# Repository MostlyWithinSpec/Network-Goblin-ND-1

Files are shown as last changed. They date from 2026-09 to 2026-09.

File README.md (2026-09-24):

<div align="center">

# 🧌 Network Goblin ND-1

### *"Here be packets."*

**A DIY handheld Ethernet cable & network tester built around a ~$2 PHY chip.**

Cable fault detection (TDR), length estimation, link / DHCP / ping / traceroute,
and switch-port identification (LLDP/CDP) — on a touchscreen, in your pocket,
for a fraction of the cost of a commercial LinkRunner or Pockethernet.

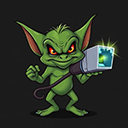
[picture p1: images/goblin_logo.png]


</div>

---

## What is it?

The Network Goblin is a homemade network technician's tool. Plug it into a
drop and it tells you what's wrong with the cable or the connection: is the
cable broken, where's the break, is it linking, is it getting DHCP, can it
reach the gateway and the internet, and *which switch port am I plugged into*.

It's built on the surprising discovery that the **Microchip LAN8742**
Ethernet PHY has a built-in **TDR (Time Domain Reflectometry)** engine — the
same technique the expensive testers use to locate cable faults — that you
can drive directly over the PHY management bus. Pair that with an ESP32, a
touchscreen, and a battery, and you've got a real cable tester for pocket
change.

> ⚠️ **Project status: working prototype.** The dev-kit build is fully
> functional. A custom PCB is in development. This is an active,
> learning-in-public hobby project — expect rough edges.

---

## ✨ Features

### Working now
- ✅ **Cable fault detection (TDR)** — detects **OPEN / SHORT / GOOD** on the
  two active pairs and reports **distance to the fault** in feet.
- ✅ **Per-pair status** — pairs 1-2 and 3-6 tested individually.
- ✅ **Link status** — up/down, 10/100, full/half duplex.
- ✅ **DHCP test** — IP, subnet, gateway, DNS.
- ✅ **Ping** — gateway and Google (8.8.8.8), one tap, no typing.
- ✅ **Traceroute** — gateway and Google.
- ✅ **Switch identification (LLDP / CDP)** — discovers the **switch name,
  port, and VLAN** you're plugged into. Works with a temporary capture that
  pauses networking, then restores it automatically.
- ✅ **Port flash** — blinks the switch's port LED (by cycling the link) so
  you can physically find which port your cable goes to. No SNMP or creds.
- ✅ **AutoTest** — one button: checks the cable, and if it's good, pings the
  gateway and internet, then shows a PASS/FAIL rollup + cable length.
- ✅ **Touchscreen GUI** (LVGL) with a light "business" theme and a dark
  "goblin" hacker theme.
- ✅ **Serial console** — every function is also available over USB serial
  (`id`, `link`, `cable`, `tdr`, `pairs`, `ping <host>`, `trace <host>`,
  `switch`, `flash`).
- ✅ **Settings persistence** — remember theme, units, calibration.

### Known limitations / rough edges
- ⚠️ **Linked-cable length needs tuning.** When plugged into a live switch,
  cable length comes from the PHY's CBLN register, which is *coarse* and
  currently **over-reports** (an ~18 ft cable may read ~100 ft). It needs
  per-chip calibration against known cable lengths. **Open-cable (TDR) fault
  distance is accurate**; linked-length is a rough estimate for now.
- ⚠️ **Switch ID and networking are mutually exclusive** — identifying the
  switch pauses networking for ~45s, then restores it. (By design; keeps it
  rock-solid.)
- ⚠️ **Port flash is switch-dependent** — the link *does* cycle, but some
  switches (many UniFi/UBNT) don't visibly blink the port LED on link loss.
  Cisco and most managed switches will.
- ⚠️ **Traceroute** doesn't yet display intermediate hop addresses reliably.
- ⚠️ **Pairs 4-5 and 7-8** can't be tested at 10/100 (those pairs aren't
  driven). Shown honestly as "n/a." Full 4-pair wiremap needs a gigabit PHY.
- ⚠️ **No battery gauge** on the dev-kit build (planned for the custom PCB).

### Planned / roadmap
- 🔜 **Custom destination** for ping / traceroute (on-screen entry).
- 🔜 **Linked-length calibration** baked in.
- 🔜 **Battery percentage** (custom PCB).
- 🔜 **Screenshot / result logging to SD.**

### The bigger idea — "ND-2"
A future, more powerful sibling based on a Linux SBC (e.g. an Orange Pi with
a gigabit NIC): real 4-pair certification, packet capture / Wireshark,
iperf throughput, inline tap / port-mirror target, and security-oriented
tooling. ND-1 stays the cheap, instant-on pocket tester; ND-2 is the
Linux-powered multitool. (Concept stage.)

---

## 🛠️ Hardware

🎉**Ordered Rev-c boards on 9/24/2026** Don't buy the PCB yet. I will update if the board is stable and working.

This runs today on an **off-the-shelf dev-kit build** — no custom PCB
required to try it. A custom board is in testing.

### Dev-kit build (replicate it now)
| Part | Notes |
|---|---|
| **ESP32 DevKit (WROOM-32)** | Must be the *classic* ESP32 — it has the built-in Ethernet MAC. **NOT** S3 / S2 / C3 (no EMAC). |
| **LAN8720 RMII module, chip-swapped to LAN8742** | The LAN8742 is footprint-compatible with the LAN8720. Desolder the 8720, reflow an 8742 in its place. This is what gives you the TDR engine. |
| **3.5" SPI touchscreen** | ST7796 driver, FT6336U capacitive touch, 320×480. |
| **Jumper wires / breadboard** | For the RMII + display wiring. |
| **(optional) LiPo + charger** | For untethered use. |

> 🔧 **Two gotchas worth knowing:**
> - The chip swap is a QFN reflow. Doable with hot air + flux + patience
>   (this project's first swap was done one-handed in a sling — it's
>   forgiving). Buy a couple of LAN8742s for spares, and mind orientation.
> - If using the same Elegoo-style ESP32, you'll need to **solder a wire to
>   GPIO0** for the PHY REFCLK.

### Parts list (dev kit)
| Part | Link |
|---|---|
| ESP32 WROOM | https://a.co/d/03k8Kfh2 |
| LAN8720 module | https://a.co/d/0iP2sltR |
| LAN8742A chip | https://ebay.io/m/x2hki5 |
| 3.5" LCD | https://www.aliexpress.us/item/3256805925926605.html |

### Wiring (dev kit)
RMII data pins on the ESP32 are **fixed in silicon**:
```
TXD0=19  TXD1=22  TX_EN=21   RXD0=25  RXD1=26  CRS_DV=27
MDC=23   MDIO=18  50 MHz CLK -> GPIO0 (from the module's oscillator)
PHY address strap = 1
```
Display / touch pins are configurable — see `ng_config.h` (all pins live in
one place; edit there first).

> ⚠️ **The GPIO0 clock quirk:** the module's 50 MHz clock feeds GPIO0, which 
> is also the boot strap pin. You can usually flash with the clock wire 
> **still connected** — but it occasionally gets stuck holding GPIO0 low at 
> boot. If a flash fails or it hangs, just **tap reset a few times** until it 
> catches and boots/uploads normally. (The custom PCB fixes this for good.)

### Custom PCB (in development)
A dedicated board with the LAN8742, ESP32, display connector, LiPo charging,
and a proper power switch is being designed. It is **not fully working yet**
(hardware bring-up in progress). Beta board files will be posted shortly.

> ⚠️ **Not recommended to order the PCB yet** — there are several known
> issues. Watch the repo; files and a BOM will come once it's validated.

---

## 💾 Firmware (Arduino)

Built with the **Arduino IDE** and **LVGL**.

### Requirements
- Arduino IDE 2.x
- **esp32 board package** (Espressif) — v3.x
- Libraries (Library Manager):
  - **lvgl** (9.x)
  - **GFX Library for Arduino** (Arduino_GFX by moononournation)
- An `lv_conf.h` configured for LVGL 9 (see LVGL's Arduino setup notes)

### Build
1. Open the `ND1_Goblin_LVGL` folder in Arduino IDE.
2. Board: **ESP32 Dev Module**. Upload speed: 115200.
3. Edit `ng_config.h` to match your wiring.
4. Upload. If it fails to connect or hangs at boot, tap reset a few times until it catches (The GUI will flash in very quickly during boot. This is how you know it is not stuck in boot low).
5. Serial Monitor @ 115200. Type `help` for commands.

First boot should print the PHY ID (`0x0007C131` for a LAN8742) — that
confirms the chip swap worked.

---

### Screenshots
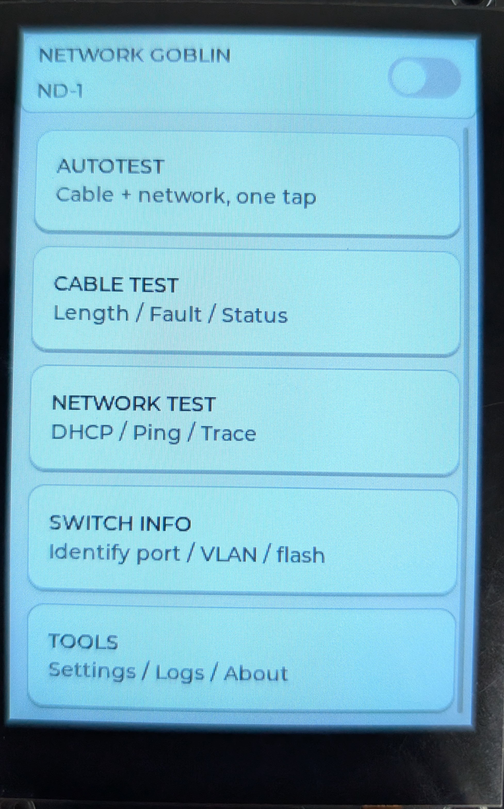
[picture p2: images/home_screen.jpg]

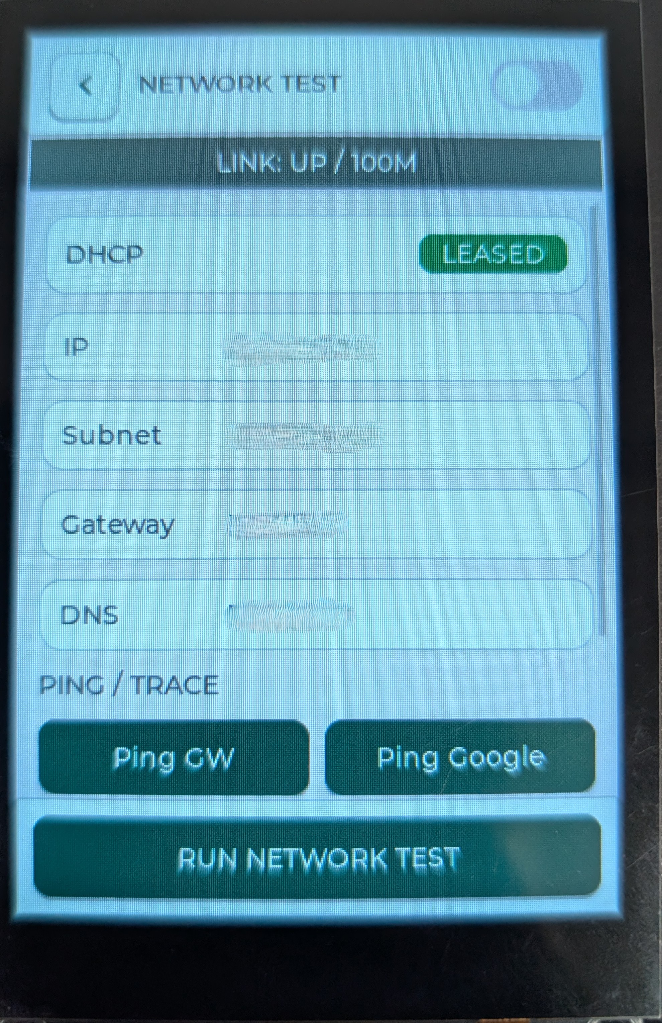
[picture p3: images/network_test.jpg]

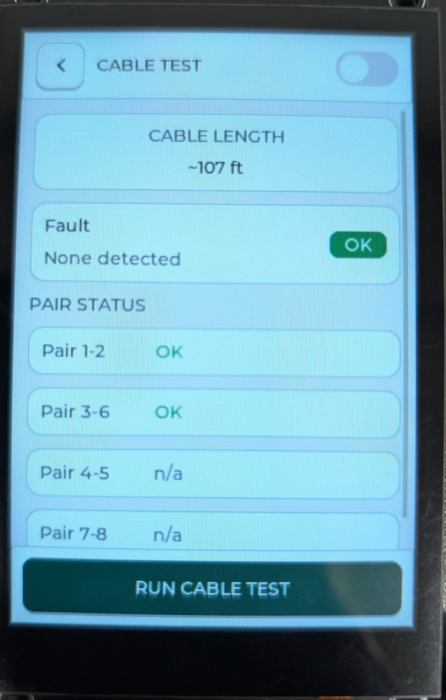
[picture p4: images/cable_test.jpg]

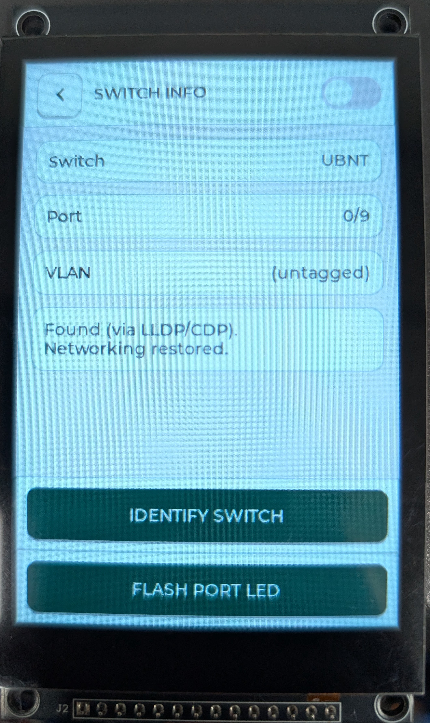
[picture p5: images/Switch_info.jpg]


## 📁 Repo layout
```
network-goblin/
├── README.md
├── LICENSE
├── CONTRIBUTING.md
├── .gitignore
├── images/                   (screenshots / build photos)
└── ND1_Goblin_LVGL/          (open this folder in Arduino IDE)
    ├── ND1_Goblin_LVGL.ino   main sketch (boot + loop + serial console)
    ├── ng_config.h           ALL pins / tunables — edit first
    ├── ng_eth.*              Ethernet (LAN8742) + PHY MDIO + cable length
    ├── ng_tdr.*              TDR cable fault detection (the heart of it)
    ├── ng_pairs.*            per-pair status
    ├── ng_netcmd.*           ping + traceroute
    ├── ng_lldp.*             LLDP/CDP switch ID + port flash
    ├── ng_display.*          LVGL + ST7796 + FT6336U
    └── ng_ui.*               the touchscreen UI (hand-coded LVGL)
```

---

## 🧪 A note on accuracy

This is a **hobby tool, not a certified cable analyzer.** The TDR fault
distance is calibrated against a handful of known cables and gets you
"close" — great for *finding a break*, not for certification. Linked-cable
length (CBLN) is coarse and needs tuning. Treat readings as a very useful
sanity check, not gospel. If you need certified results, buy the $2,000
tool. If you want to know "is this drop broken, and roughly where" for the
price of a nice dinner — welcome to the Goblin. 🧌

---

## 🤝 Contributing

This is an active, learning-in-public project by a self-taught tinkerer.
Issues, PRs, ideas, and "you did this the hard way, here's better" comments
are all welcome. If you build one, I'd love to see it. See
[CONTRIBUTING.md](CONTRIBUTING.md).

> Full disclosure: a lot of this was built with heavy help from AI as a
> learning aid. It's a hobbyist's project, shared openly. Improvements from
> people who actually know what they're doing are very welcome.

## 📜 License

**MIT** — see [LICENSE](LICENSE). Do whatever you want with it. No warranty.
Don't blame the goblin if your cable's still broken.

---

<div align="center">

*Built one-handed, in a sling, after shoulder surgery, out of spite for a
$2,000 price tag. The Goblin endures.* 🧌🔌⚡

</div>

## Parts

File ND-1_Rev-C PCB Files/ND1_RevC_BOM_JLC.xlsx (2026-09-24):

Comment | Designator | Footprint | JLCPCB Part #（optional）
470pF | C1 | C0603 | C107092
1uF | C2 | C0603 | C29936
100nF | C3,C4,C7,C8,C16,C21,C22,C24,C26,C27,C28,C29,C30 | C0603 | C14663
10uF | C9,C10,C11 | C0805 | C15850
22uF | C12,C13,C14,C15,C25 | C0805 | C45783
1uF | C17,C20,C23 | C0603 | C15849
4.7uF | C18,C19 | C0805 | C1779
1.25-2P | CN2 | CONN-SMD_1.25-2P | C393945
BAT54WS | D1 | D_SOD-323 | C124205
HR911105A | J1 | RJ45-TH_HR911105A | C12074
1.5uH | L1 | IND-SMD_L4.0-W4.0-A | C3033018
MMBT5551(RANGE:200-300) | Q1 | SOT-23-3_L2.9-W1.3-P1.90-LS2.4-BR | C2145
10kΩ | R1,R2,R9,R11,R12,R34,R40,R45,R46,R47 | R0603 | C25804
1.5kΩ | R3 | R0603 | C2930050
12.1kΩ | R4 | R0603 | C2930059
2kΩ | R13 | R0603 | C22975
4.7kΩ | R14,R17,R18 | R0402 | C25900
1.27kΩ | R15 | R0603 | C22836
47kΩ | R16,R33 | R0603 | C25819
5.1kΩ | R21,R22 | R0402 | C25905
180kΩ | R23 | R0603 | C22827
49.9Ω | R25,R28,R29,R30 | R0402 | C25120
1MΩ | R27 | R0603 | C22935
33Ω | R31,R32 | R_0603_1608Metric | C23140
470Ω | R35 | R_0603_1608Metric | C23179
10Ω | R36,R37,R38 | R_0402_1005Metric | C25077
4.7kΩ | R39 | R_0603_1608Metric | C23162
332Ω | R41,R42 | R_0603_1608Metric | C23007
100kΩ | R43,R44,R48 | R_0603_1608Metric | C25803
TS-1187A-B-A-B | SW1,SW2 | SW-SMD_4P-L5.1-W5.1-P3.70-LS6.5-TL_H1.5 | C318884
PWR (EN switch) | SW3 | SW_SPDT_PCM12 | C221841
ESP32-WROVER-E-N16R8 | U1 | WIFI-SMD_ESP32-WROVER-E | C529589
LAN8742A-CZ-TR | U2 | QFN-24_L4.0-W4.0-P0.50-TL-EP2.5 | C621424
CH9102F | U3 | QFN-24_L4.0-W4.0-P0.50-BL-EP2.5 | C2858418
BQ24074RGTR | U4 | QFN-16_L3.0-W3.0-P0.50-TL-EP1.7 | C54313
TPS63020DSJR | U5 | VSON-14_L4.0-W3.0-P0.50-BL-EP_TI_DSJ | C15483
MAX17048G+T10 | U6 | TDFN-8_L2.0-W2.0-P0.50-BL-EP1.2 | C2682616
FPC 0.5-14P HYH2.0 | U7 | FPC-SMD_14P-P0.50_FPC-0.5-14P-HYH2.0 | C6364661
MMZ1608Y152BTA00 | U8 | L0603 | C275454
SRV05-4 | U9 | SOT-23-6 | C13612
74LVC2G126 | U10 | VSSOP-8_2.3x2mm_P0.5mm | C2652104
TYPE-C-31-M-12 | USBC1 | USB-C_SMD-TYPE-C-31-M-12_1 | C165948
50MHz | Y1 | Oscillator_SMD_Abracon_ASE-4Pin_3.2x2.5mm | C717684

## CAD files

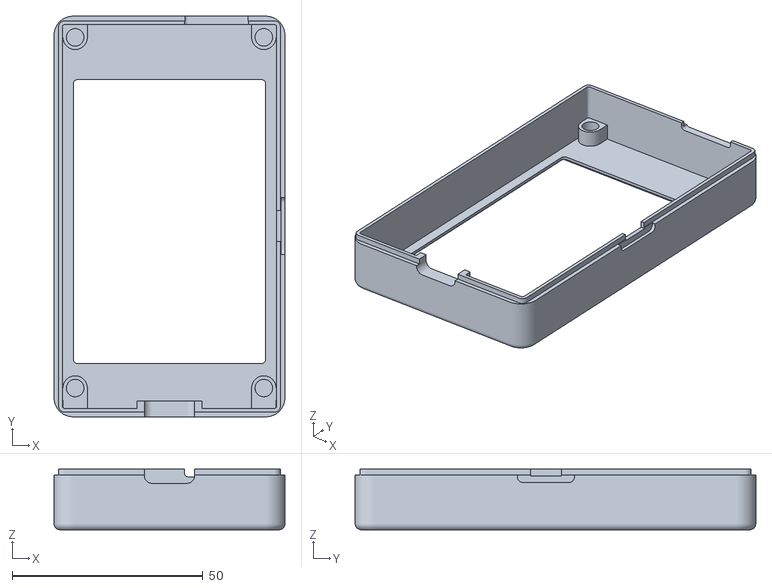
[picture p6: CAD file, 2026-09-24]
ND1_RevC_Case_Files/ND1_FrontShell.stl
60.6 x 105.1 x 15.9

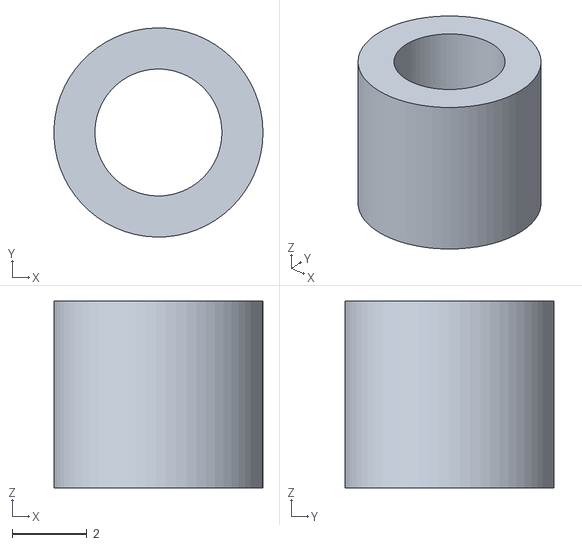
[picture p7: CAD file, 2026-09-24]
ND1_RevC_Case_Files/ND1_Spacer_print_x4.stl
5.60 x 5.60 x 5.00

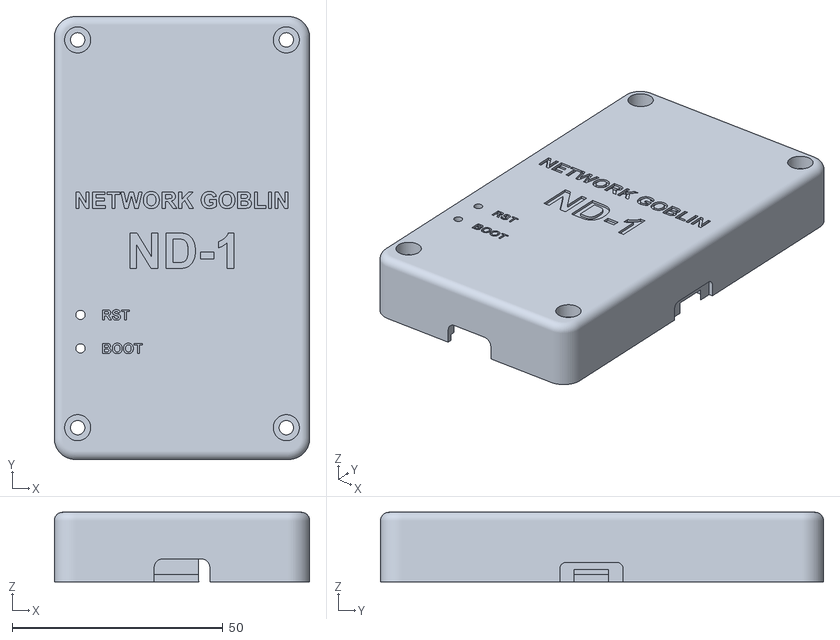
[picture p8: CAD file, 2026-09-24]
ND1_RevC_Case_Files/ND1_BackCover.stl
60.6 x 105.1 x 16.5

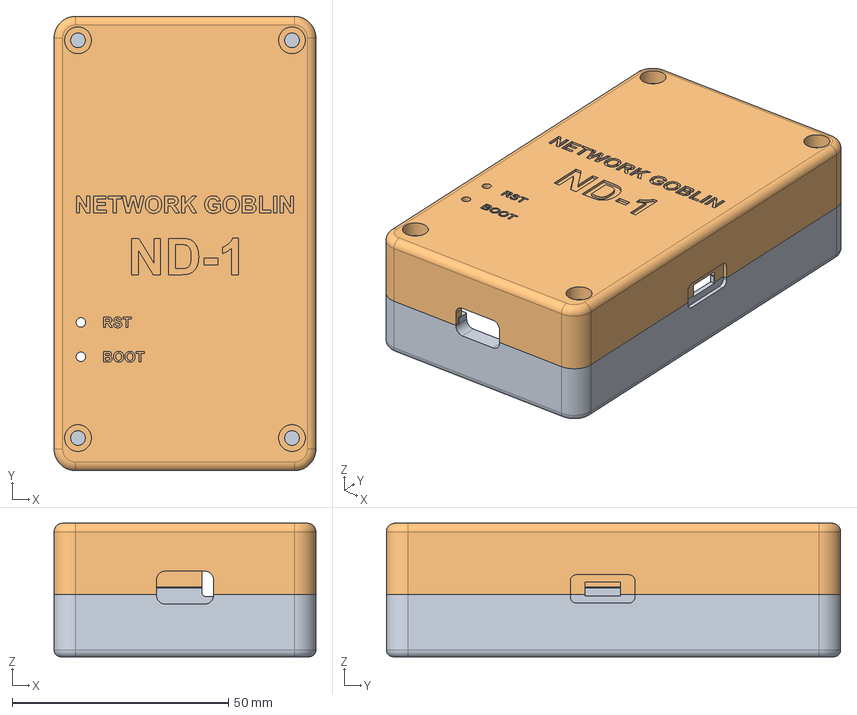
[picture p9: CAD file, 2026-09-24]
ND1_RevC_Case_Files/ND1_Case_parts.step
60.6 x 105.1 x 30.9 mm
FrontShell
BackCover
Spacer

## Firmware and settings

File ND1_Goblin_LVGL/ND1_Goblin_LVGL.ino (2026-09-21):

/* ============================================================
 *  Network Goblin ND-1  -  Arduino + LVGL firmware
 *  "Here be packets."
 * ------------------------------------------------------------
 *  Serial commands: id | link | cable | tdr | pairs | switch 
                  | Flash | ping <host> | trace <host> | help
 * ============================================================ */
#include "ng_config.h"
#include "ng_eth.h"
#include "ng_tdr.h"
#include "ng_pairs.h"
#include "ng_netcmd.h"
#include "ng_display.h"
#include "ng_ui.h"
#include "ng_lldp.h" 
#include "ng_goblin.h"
#include "Preferences.h"

static void banner(){
  Serial.println();
  Serial.println("=====================================");
  Serial.printf (" NETWORK GOBLIN %s  fw %s\n", NG_MODEL, NG_FW);
  Serial.println(" " NG_TAGLINE);
  Serial.println("=====================================");
}

static void serialCmd(){
  static char buf[40]; static uint8_t n=0;
  while(Serial.available()){
    char c=Serial.read();
    if(c=='\n'||c=='\r'){ buf[n]=0;
      if(!strcmp(buf,"id")){ uint32_t id; if(ngPhyId(&id)) Serial.printf("[PHY] ID=0x%08X OK\n",id); else Serial.println("[PHY] read FAILED"); }
      else if(!strcmp(buf,"link")){ NgCable c2; ngCableRun(c2); Serial.printf("[LINK] %s %dMbps %s\n",c2.state,c2.speed_mbps,c2.full_duplex?"FULL":"HALF"); }
      else if(!strcmp(buf,"cable")){ NgCable c2; ngCableRun(c2); Serial.printf("[CABLE] %s len=%s cbln=0x%04X\n",c2.state,c2.length_valid?String(c2.length_ft,0).c_str():"--",c2.raw_cbln); }
      else if(!strcmp(buf,"tdr")){ NgTdrResult r; ngTdrRun(r);
        Serial.printf("MDI : %-6s ~%.1f ft [0x%04X]\n",ngTdrTypeStr(r.mdi.type),r.mdi.dist_ft,r.mdi.raw25);
        Serial.printf("MDIX: %-6s ~%.1f ft [0x%04X]\n",ngTdrTypeStr(r.mdix.type),r.mdix.dist_ft,r.mdix.raw25); }
      else if(!strcmp(buf,"pairs")){ NgWiremap w; ngPairsRun(w);
        Serial.printf("Pair 1-2: %s\n",ngPairStateStr(w.p12.state));
        Serial.printf("Pair 3-6: %s\n",ngPairStateStr(w.p36.state));
        Serial.printf("Pair 4-5: %s\n",ngPairStateStr(w.p45.state));
        Serial.printf("Pair 7-8: %s\n",ngPairStateStr(w.p78.state)); }
      else if(!strncmp(buf,"ping ",5)){ NgPingResult pr;
        if(ngPing(buf+5,4,pr)) Serial.printf("ping %s (%s): %d/%d avg %lums (min %lu/max %lu)\n",buf+5,pr.resolved_ip.c_str(),pr.recv,pr.sent,pr.avg_ms,pr.min_ms,pr.max_ms);
        else Serial.printf("ping %s: no reply\n",buf+5); }
      else if(!strncmp(buf,"trace ",6)){ Serial.printf("traceroute to %s:\n",buf+6);
        ngTraceroute(buf+6,20,[](int hop,const char* ip,uint32_t rtt,bool reached){ Serial.printf(" %2d  %-16s %lums%s\n",hop,ip,rtt,reached?"  <-- dest":""); }); }
    else if(!strcmp(buf,"switch")){
  Serial.println("[SWITCH] listening 45s (networking paused)...");
  ngLldpStart();
  uint32_t t0=millis();
  while(millis()-t0 < 45000 && !ngLldpFresh(60000)){ delay(200); }
  NgSwitchInfo si; ngLldpGet(si);
  if(si.have_lldp||si.have_cdp){
    Serial.printf("[SWITCH] name: %s\n", si.sys_name[0]?si.sys_name:"?");
    Serial.printf("[SWITCH] port: %s\n", si.port_id[0]?si.port_id:"?");
    Serial.printf("[SWITCH] vlan: %d\n", si.vlan);
  } else Serial.println("[SWITCH] nothing seen (try again / check LLDP enabled)");
  ngLldpStop();   // <-- restores networking
}
else if(!strcmp(buf,"flash")){ ngLldpPortFlash(5); }
else if(!strcmp(buf,"netcheck")){ ngLldpEnsureStopped();
  NgNet n; ngEthSnapshot(n); Serial.printf("IP: %s\n", n.got_ip?n.ip.c_str():"none"); }
      else if(!strcmp(buf,"help")){ Serial.println("cmds: id | link | cable | tdr | pairs | switch | Flash | ping <host> | trace <host> | help"); }
      else if(n>0) Serial.println("? help");
      n=0;
    } else if(n<sizeof(buf)-1) buf[n++]=c;
  }
}

void setup(){
  Serial.begin(115200);
  delay(300);

  banner();

  ngGoblinInit();

  Serial.println("[SYS] display...");
  ngDisplayBegin();

  Serial.println("[SYS] ui...");
  ngUiInit();

  ngUiShowSplash();
  ngUiSplashStatus("Initializing Ethernet...");

  Serial.println("[SYS] ethernet...");
  ngEthBegin();

  ngLldpBegin();

  uint32_t id;

  if(ngPhyId(&id)){
    Serial.printf("[PHY] ID=0x%08X swap OK\n",id);

    ngUiSplashStatus(
      "PHY........OK\n"
      "Display....OK\n"
      "Network....OK"
    );
  }

  delay(500);

  ngUiSplashAwake();

  delay(1000);

  ngUiLoadHome();

  Serial.println("[SYS] up. type 'help'. Goblin awake.");
}

void loop(){
  ngDisplayTick();
  ngUiService();
  serialCmd();
}

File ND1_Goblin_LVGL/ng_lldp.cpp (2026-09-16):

/* ng_lldp.cpp - LLDP / CDP discovery + port flash  (v3 - on-demand)
 * ------------------------------------------------------------
 *  Capture is ON-DEMAND and MUTUALLY EXCLUSIVE with networking.
 *
 *    ngLldpStart()  -> installs a frame hook that CONSUMES frames.
 *                      Networking (DHCP/ping) is paused while active.
 *    ngLldpStop()   -> removes the hook and RESTARTS Ethernet so the
 *                      normal stack works again. No frame-forwarding
 *                      trickery needed - we just rebuild the driver.
 *
 *  Any other tool (network test, ping, etc.) should call
 *  ngLldpEnsureStopped() first, which restores networking if a
 *  capture was left running.
 *
 *  This trades "both at once" for "rock solid" - exactly the tradeoff
 *  you asked for.
 * ============================================================ */
#include "ng_lldp.h"
#include "ng_config.h"
#include <WiFi.h>
#include <ETH.h>
#include "esp_eth.h"
#include "freertos/FreeRTOS.h"
#include "freertos/task.h"
#include <string.h>

extern bool ngPhyRead(uint8_t reg, uint16_t* val);
extern bool ngPhyWrite(uint8_t reg, uint16_t val);

static NgSwitchInfo s_info;
static portMUX_TYPE s_mux = portMUX_INITIALIZER_UNLOCKED;
static esp_eth_handle_t s_eth = NULL;
static volatile bool s_flashing = false;
static volatile bool s_capturing = false;

static uint16_t be16(const uint8_t* b){ return ((uint16_t)b[0]<<8)|b[1]; }
static void copyStr(char* dst, size_t dstsz, const uint8_t* src, int len){
  if(len<0) len=0; if((size_t)len>=dstsz) len=dstsz-1;
  memcpy(dst,src,len); dst[len]=0;
}

static void parse_lldp(const uint8_t* p, uint32_t length){
  uint32_t i=14; char name[48]={0},port[48]={0}; int vlan=-1; bool got=false;
  while(i+2<=length){
    uint16_t hdr=be16(&p[i]); uint8_t type=(hdr>>9)&0x7F; uint16_t len=hdr&0x1FF;
    i+=2; if(i+len>length) break; const uint8_t* v=&p[i];
    if(type==0) break;
    else if(type==2){ if(len>1) copyStr(port,sizeof(port),v+1,len-1); got=true; }
    else if(type==5){ copyStr(name,sizeof(name),v,len); got=true; }
    else if(type==127 && len>=4){
      uint32_t oui=((uint32_t)v[0]<<16)|((uint32_t)v[1]<<8)|v[2]; uint8_t sub=v[3];
      if(oui==0x0080C2 && sub==0x01 && len>=6){ vlan=be16(&v[4]); got=true; }
    }
    i+=len;
  }
  if(got){
    portENTER_CRITICAL(&s_mux);
    s_info.have_lldp=true;
    if(name[0]) strncpy(s_info.sys_name,name,sizeof(s_info.sys_name));
    if(port[0]) strncpy(s_info.port_id,port,sizeof(s_info.port_id));
    if(vlan>=0) s_info.vlan=vlan;
    s_info.last_seen_ms=millis();
    portEXIT_CRITICAL(&s_mux);
  }
}
static void parse_cdp(const uint8_t* p, uint32_t length){
  uint32_t i=22+4; char name[48]={0},port[48]={0}; int vlan=-1; bool got=false;
  while(i+4<=length){
    uint16_t type=be16(&p[i]); uint16_t len=be16(&p[i+2]);
    if(len<4||i+len>length) break; uint16_t vlen=len-4; const uint8_t* v=&p[i+4];
    if(type==0x0001){ copyStr(name,sizeof(name),v,vlen); got=true; }
    else if(type==0x0003){ copyStr(port,sizeof(port),v,vlen); got=true; }
    else if(type==0x000A && vlen>=2){ vlan=be16(v); got=true; }
    i+=len;
  }
  if(got){
    portENTER_CRITICAL(&s_mux);
    s_info.have_cdp=true;
    if(name[0]) strncpy(s_info.sys_name,name,sizeof(s_info.sys_name));
    if(port[0]) strncpy(s_info.port_id,port,sizeof(s_info.port_id));
    if(vlan>=0) s_info.vlan=vlan;
    s_info.last_seen_ms=millis();
    portEXIT_CRITICAL(&s_mux);
  }
}

// Capture hook: while capturing, we CONSUME every frame (free it).
// Networking is intentionally paused during a capture window.
static esp_err_t capture_hook(esp_eth_handle_t h, uint8_t* buf, uint32_t len, void* priv){
  if(len>=14){
    uint16_t et=be16(&buf[12]);
    if(et==0x88CC) parse_lldp(buf,len);
    else if(buf[0]==0x01&&buf[1]==0x00&&buf[2]==0x0C&&buf[3]==0xCC&&buf[4]==0xCC&&buf[5]==0xCC)
      parse_cdp(buf,len);
  }
  free(buf);          // consume - we are not networking right now
  return ESP_OK;
}

void ngLldpBegin(){
  memset(&s_info,0,sizeof(s_info)); s_info.vlan=-1;
  s_eth = ETH.handle();
  s_capturing = false;
  Serial.println("[LLDP] ready (on-demand capture)");
}

// Start a capture window: install the consuming hook.
void ngLldpStart(){
  if(!s_eth) s_eth = ETH.handle();
  if(!s_eth){ Serial.println("[LLDP] no eth handle"); return; }
  // fresh results for this window
  portENTER_CRITICAL(&s_mux);
  s_info.have_lldp=false; s_info.have_cdp=false; s_info.vlan=-1;
  s_info.sys_name[0]=0; s_info.port_id[0]=0;
  portEXIT_CRITICAL(&s_mux);
  esp_eth_update_input_path(s_eth, capture_hook, NULL);
  s_capturing = true;
  Serial.println("[LLDP] capture started (networking paused)");
}

// Stop capture and RESTORE networking by restarting Ethernet.
void ngLldpStop(){
  if(!s_capturing) return;
  s_capturing = false;
  // Rebuild the Ethernet driver so the normal stack input is restored.
  // (Cleaner than trying to re-inject the default handler ourselves.)
  ETH.end();
  delay(50);
  ETH.begin(NG_ETH_PHY_TYPE, NG_ETH_PHY_ADDR, NG_ETH_MDC, NG_ETH_MDIO,
            NG_ETH_PHY_POWER, NG_ETH_CLK_MODE);
  s_eth = ETH.handle();
  Serial.println("[LLDP] capture stopped, networking restored");
}

// Call this from any other tool before it needs the network.
void ngLldpEnsureStopped(){ if(s_capturing) ngLldpStop(); }

bool ngLldpCapturing(){ return s_capturing; }

void ngLldpGet(NgSwitchInfo& out){
  portENTER_CRITICAL(&s_mux); out=s_info; portEXIT_CRITICAL(&s_mux);
}
bool ngLldpFresh(uint32_t max_age_ms){
  portENTER_CRITICAL(&s_mux);
  bool any=s_info.have_lldp||s_info.have_cdp;
  uint32_t age=millis()-s_info.last_seen_ms;
  portEXIT_CRITICAL(&s_mux);
  return any && (age<=max_age_ms);
}

// ---- port flash ----
static void flashTask(void* arg){
  int cycles=(int)(intptr_t)arg;
  Serial.printf("[FLASH] starting %d cycles (watch the switch port LED)\n", cycles);
  for(int i=0;i<cycles && s_flashing;i++){
    uint16_t bmcr=0;
    ngPhyRead(0,&bmcr);
    ngPhyWrite(0, bmcr | (1<<11));                 // power-down -> link DOWN
    Serial.printf("[FLASH] cycle %d: link DOWN\n", i+1);
    vTaskDelay(pdMS_TO_TICKS(2000));
    ngPhyRead(0,&bmcr);
    ngPhyWrite(0, (bmcr & ~(1<<11)) | (1<<9));      // power-up + restart AN
    Serial.printf("[FLASH] cycle %d: link UP\n", i+1);
    vTaskDelay(pdMS_TO_TICKS(2500));
  }
  Serial.println("[FLASH] done");
  s_flashing=false;
  vTaskDelete(NULL);
}
void ngLldpPortFlash(int cycles){
  if(s_flashing){ Serial.println("[FLASH] already running"); return; }
  if(!s_eth) s_eth = ETH.handle();
  if(!s_eth){ Serial.println("[FLASH] no eth handle"); return; }
  s_flashing=true;
  xTaskCreate(flashTask,"portflash",3072,(void*)(intptr_t)cycles,5,NULL);
}

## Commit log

2026-09-16 Delete ND1_Goblin_LVGL/ng_ui.cpp
    Replacing with corrected file to patch memory leak when switching to dark mode.
    [ng_ui.cpp]
2026-09-16 Delete ND1_Goblin_LVGL directory
    Removing to add current build
2026-09-24 Add files via upload
    Uploaded REV-C PCB
    [ND1_RevC_BOM_JLC.xlsx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]
2026-09-24 Add files via upload
    Uploaded case files for Rev C PCB.
    [ND1_BackCover.stl, ND1_Case_parts.step, ND1_FrontShell.stl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]
